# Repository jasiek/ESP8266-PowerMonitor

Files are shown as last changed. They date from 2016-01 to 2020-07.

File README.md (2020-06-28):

# ESP8266-PowerMonitor

See this project on 

Uses [Lets Control It/ESP Easy](https://www.letscontrolit.com/).

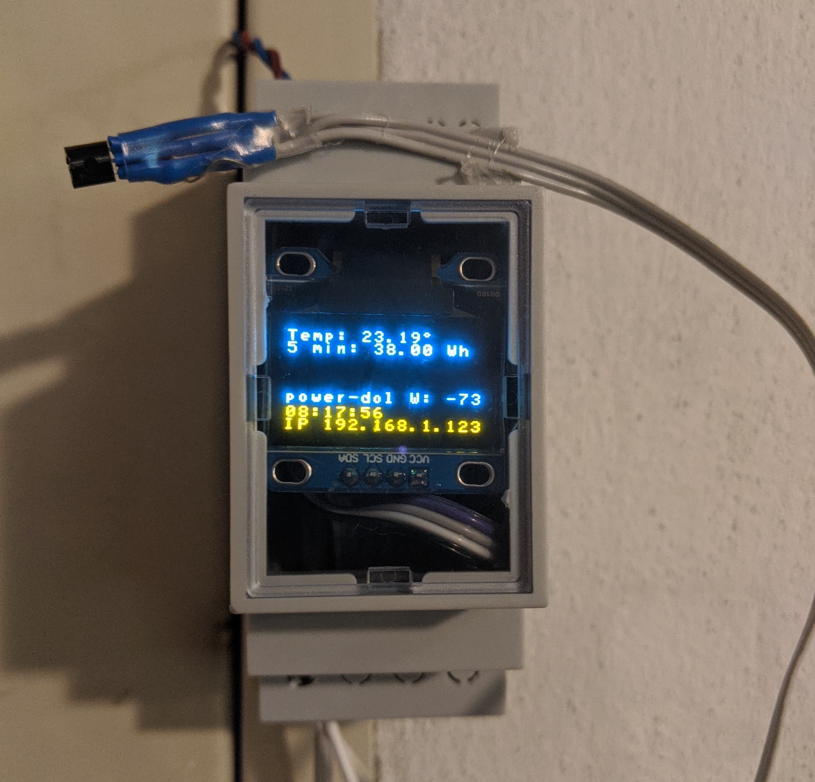
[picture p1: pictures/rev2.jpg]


## Programming

Download the latest [ESP Easy Mega release](https://github.com/letscontrolit/ESPEasy/releases).

Install [esptool.py](https://github.com/espressif/esptool). Hook up a USB-to-serial adapter to the board.

Short `_PROG` & `GND` and press RESET.

Find the right firmware file (`normal_ESP8266_4M1M`) and run:

```
$ esptool.py --port /dev/cu.usbserial-14120 --baud 115200 write_flash 0 ESP_Easy_mega_20200516_normal_ESP8266_4M1M.bin
```

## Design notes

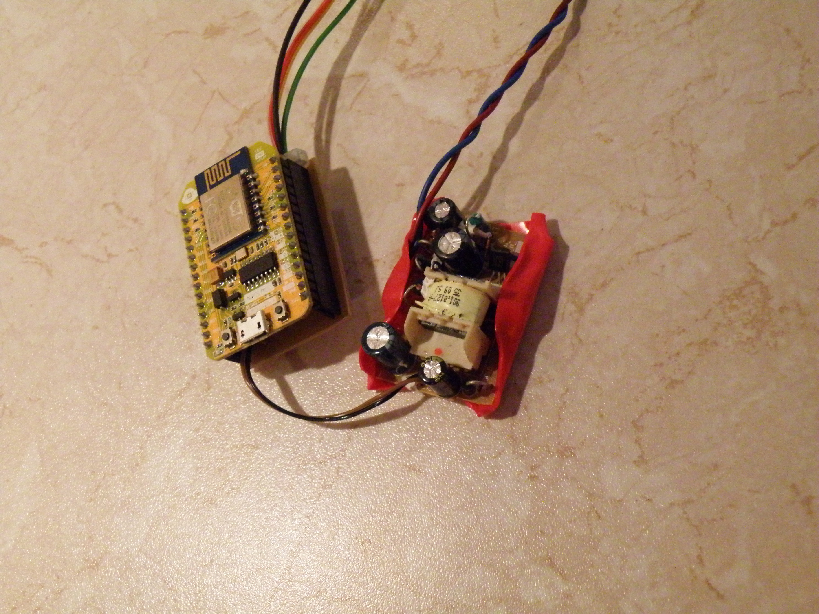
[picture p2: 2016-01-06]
pictures/NO_PIR_bare2.jpg

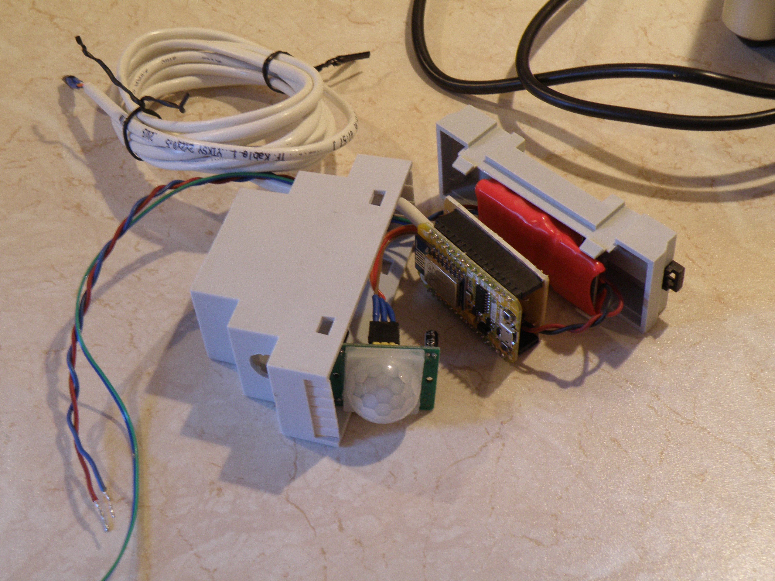
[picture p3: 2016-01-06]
pictures/PIR_exploded.jpg

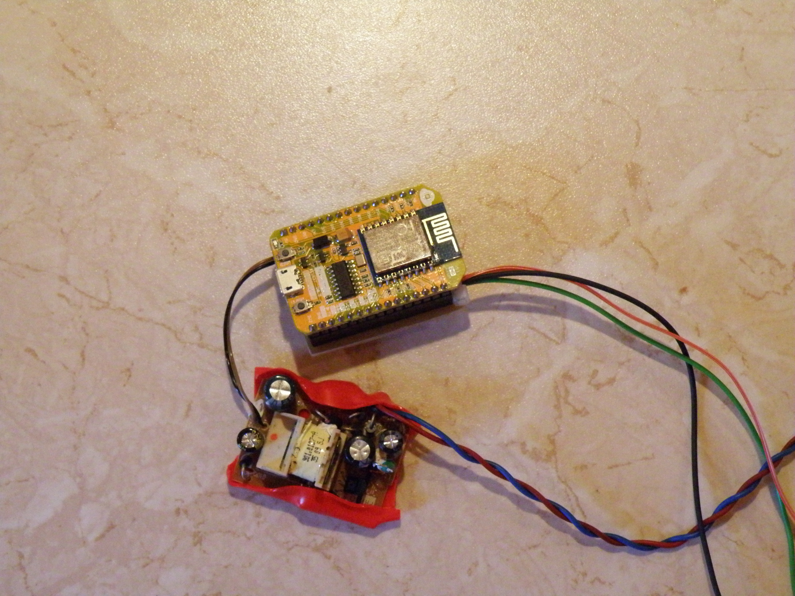
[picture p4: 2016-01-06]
pictures/NO_PIR_bare.jpg

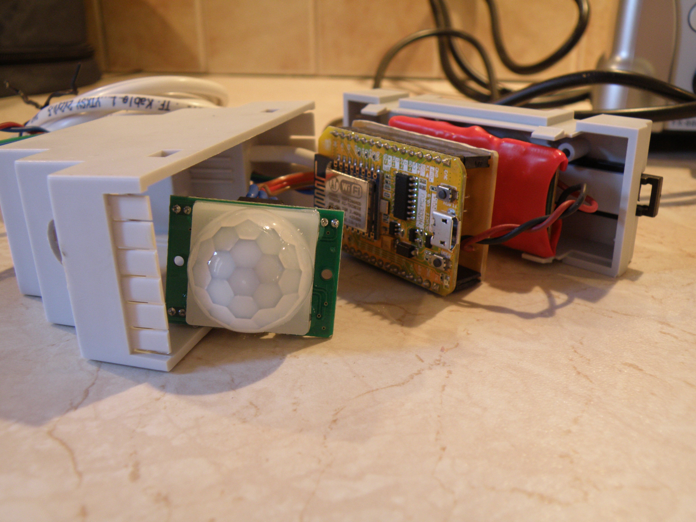
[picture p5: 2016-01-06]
pictures/PIR_exploded2.jpg

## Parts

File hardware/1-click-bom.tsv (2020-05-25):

References | Qty | Description
C1 | 1 | C 0.1uF Unpolarized capacitor 1206 3216Metric Pad1.42x1.75mm HandSolder
C2 | 1 | CP 10uF Polarized capacitor Elec 4x5.3
C3 | 1 | C 100nF Unpolarized capacitor 1206 3216Metric Pad1.42x1.75mm HandSolder
F1 | 1 | Polyfuse 100mA Resettable fuse, polymeric positive temperature coefficient Fuse 1206 3216Metric Pad1.42x1.75mm HandSolder
J1 | 1 | Conn 01x02 Male CONN PULSE Generic connector, single row, 01x02, script generated (kicad-library-utils/schlib/autogen/connector/) PinHeader 1x02 P2.54mm Vertical
J2 | 1 | Conn 01x05 Male CONN PROG Generic connector, single row, 01x05, script generated (kicad-library-utils/schlib/autogen/connector/) PinHeader 1x05 P2.54mm Vertical
J3 | 1 | Conn 01x02 Male CONN AC Generic connector, single row, 01x02, script generated (kicad-library-utils/schlib/autogen/connector/) TerminalBlock bornier-2 P5.08mm
J4 | 1 | Conn 01x03 Male CONN TEMP Generic connector, single row, 01x03, script generated (kicad-library-utils/schlib/autogen/connector/) PinHeader 1x03 P2.54mm Vertical
J5 | 1 | Conn 01x04 Male CONN I2C Generic connector, single row, 01x04, script generated (kicad-library-utils/schlib/autogen/connector/) PinHeader 1x04 P2.54mm Vertical
JP1 | 1 | SolderJumper 2 Open 3.3V BYPASS Solder Jumper, 2-pole, open SolderJumper-2 P1.3mm TrianglePad1.0x1.5mm
PS1 | 1 | HLK-PM03 Compact AC/DC board mount power module 3W 5V Converter ACDC HiLink HLK-PMxx
R1, R2, R4, R6, R5 | 5 | R 10k Resistor 1206 3216Metric Pad1.42x1.75mm HandSolder
R3 | 1 | R 470 Resistor 1206 3216Metric Pad1.42x1.75mm HandSolder
R7 | 1 | R 4.7k Resistor 1206 3216Metric Pad1.42x1.75mm HandSolder
SW1 | 1 | SW DIP x01 RESET 1x Switch, Single Pole Throw (SPST) switch, small symbol Push 1P1T NO 6x6mm H9.5mm
U1 | 1 | AMS1117-3.3 1A Low Dropout regulator, positive, 1.5V fixed output, SOT-223 SOT-223-3 TabPin2
U2 | 1 | ESP-12F 802.11 b/g/n Wi-Fi Module ESP-12E

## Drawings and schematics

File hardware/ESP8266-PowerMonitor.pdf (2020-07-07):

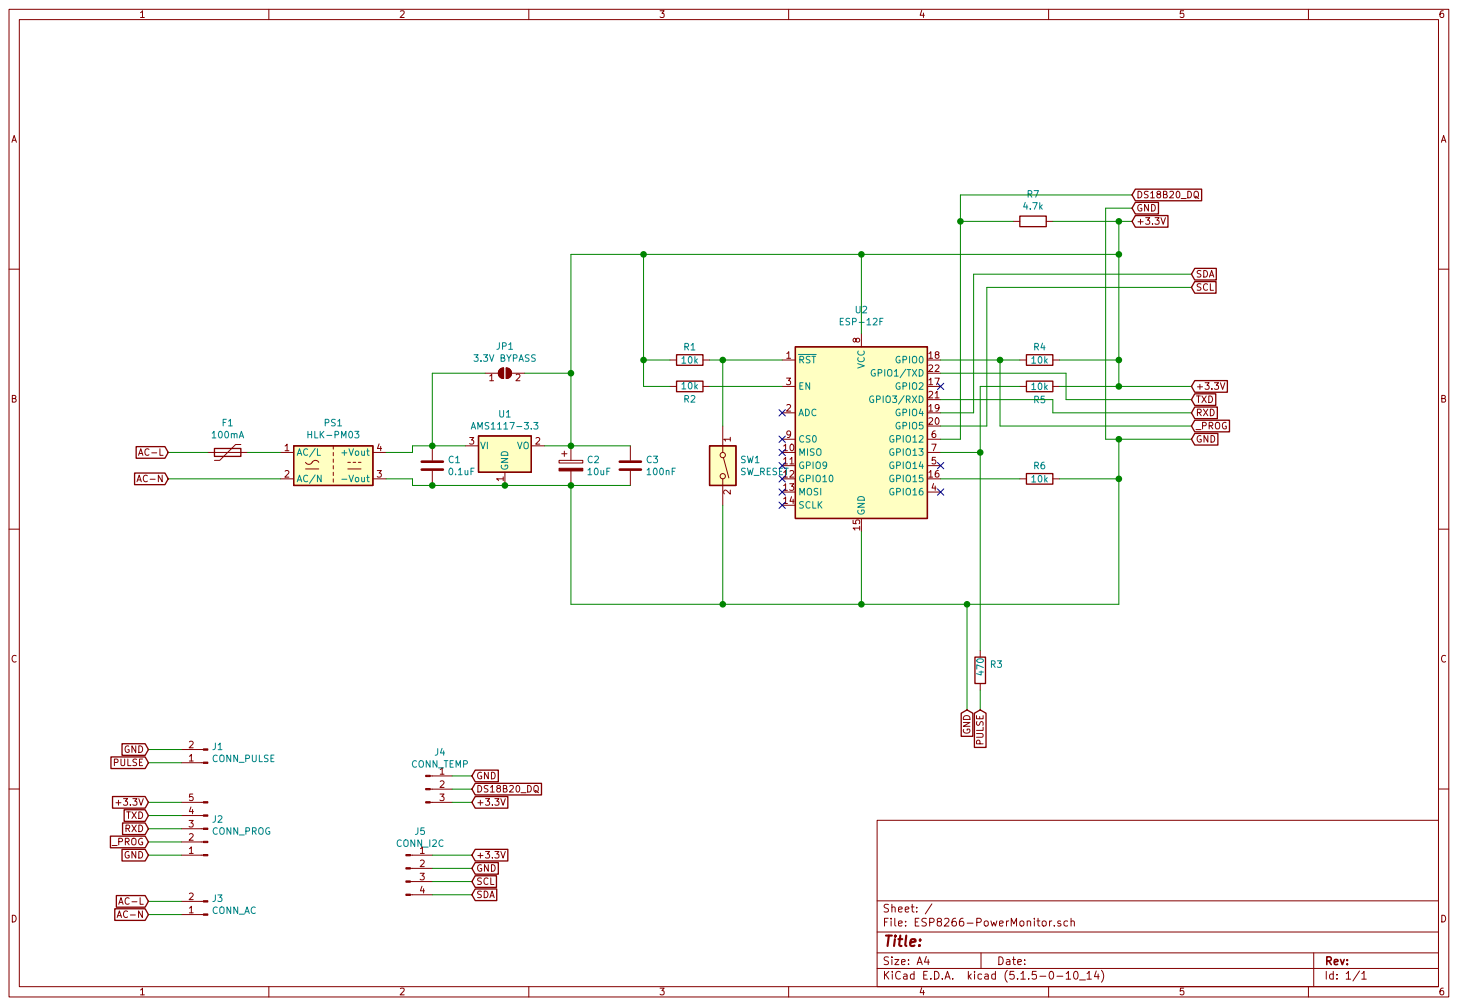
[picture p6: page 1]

Id: 1/1 Title: File: ESP8266-PowerMonitor.sch Sheet: /

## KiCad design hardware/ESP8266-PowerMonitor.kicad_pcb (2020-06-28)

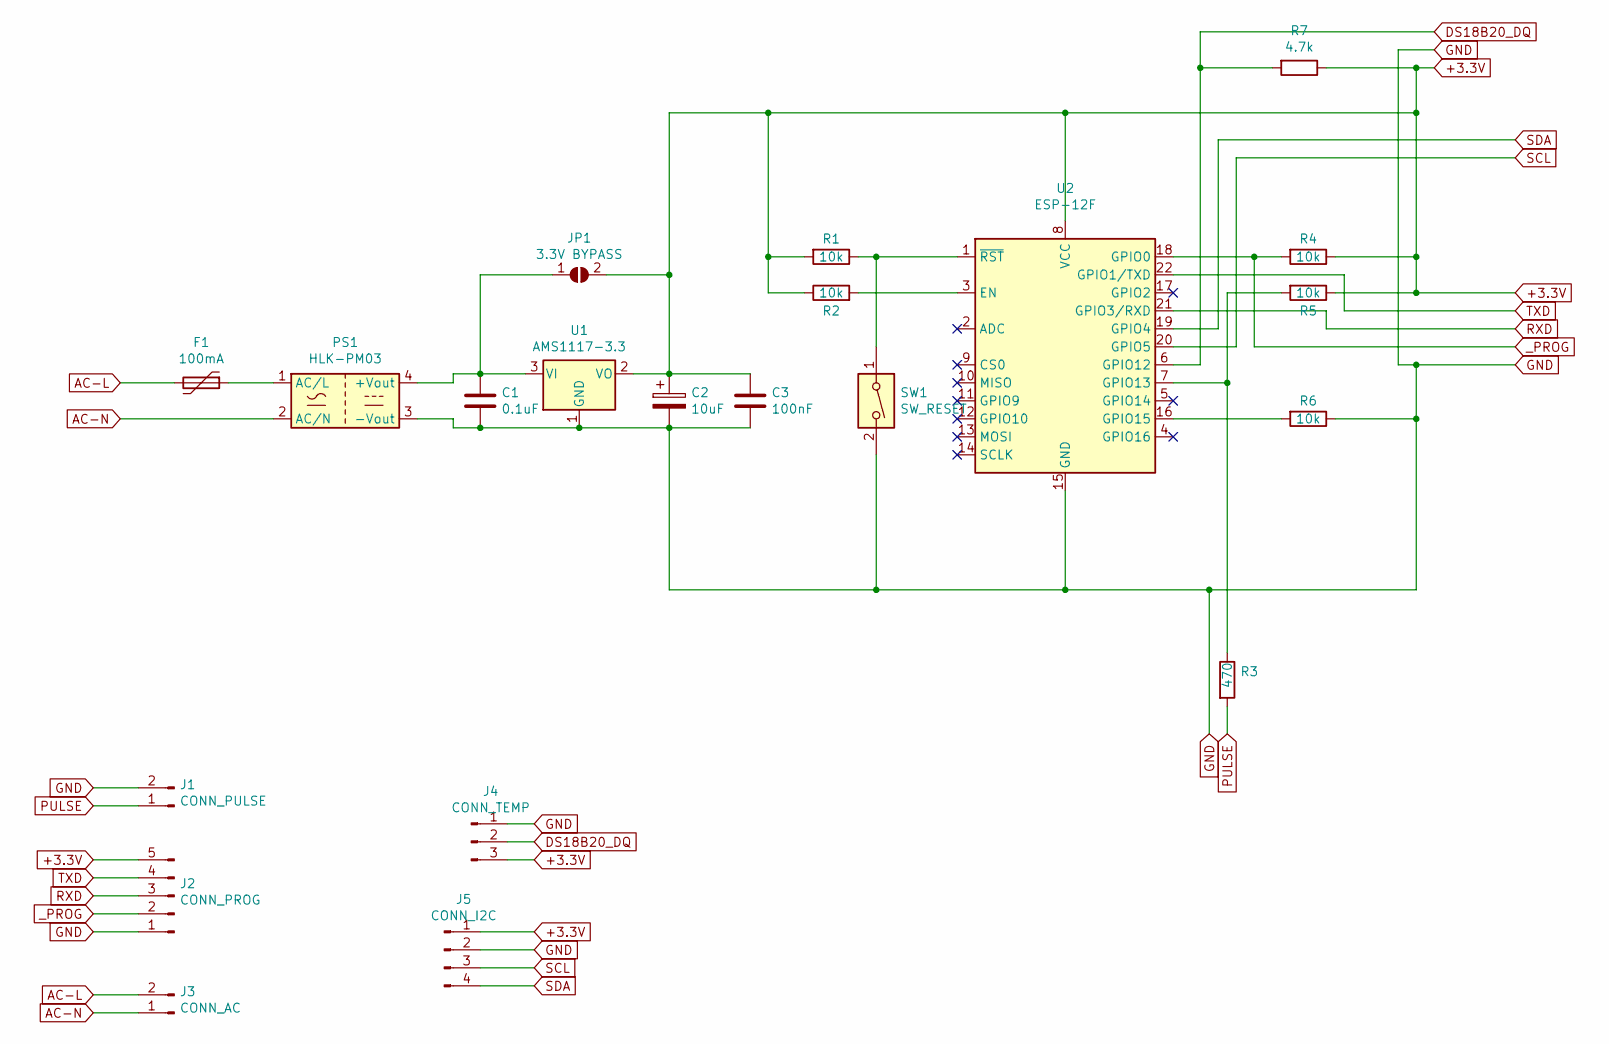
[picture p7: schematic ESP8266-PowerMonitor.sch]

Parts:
C1: 0.1uF; C_1206_3216Metric_Pad1.42x1.75mm_HandSolder
C2: 10uF; CP_Elec_4x5.3
C3: 100nF; C_1206_3216Metric_Pad1.42x1.75mm_HandSolder
F1: 100mA; Fuse_1206_3216Metric_Pad1.42x1.75mm_HandSolder
J1: CONN_PULSE; PinHeader_1x02_P2.54mm_Vertical
J2: CONN_PROG; PinHeader_1x05_P2.54mm_Vertical
J3: CONN_AC; TerminalBlock_bornier-2_P5.08mm
J4: CONN_TEMP; PinHeader_1x03_P2.54mm_Vertical
J5: CONN_I2C; PinHeader_1x04_P2.54mm_Vertical
JP1: 3.3V BYPASS; SolderJumper-2_P1.3mm_Open_TrianglePad1.0x1.5mm
PS1: HLK-PM03; Converter_ACDC_HiLink_HLK-PMxx
R1, R2, R4, R5, R6: 10k; R_1206_3216Metric_Pad1.42x1.75mm_HandSolder
R3: 470; R_1206_3216Metric_Pad1.42x1.75mm_HandSolder
R7: 4.7k; R_1206_3216Metric_Pad1.42x1.75mm_HandSolder
SW1: SW_RESET; SW_Push_1P1T_NO_6x6mm_H9.5mm
U1: AMS1117-3.3; SOT-223-3_TabPin2
U2: ESP-12F; ESP-12E

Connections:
+3.3V: C2.1, C3.1, J2.5, J4.3, J5.1, JP1.2 (B), R1.2, R2.1, R4.1, R5.1, R7.1, U1.2 (VO), U2.8 (VCC)
AC-L: F1.2, J3.2
AC-N: J3.1, PS1.2 (AC/N)
DS18B20_DQ: J4.2, R7.2, U2.6 (GPIO12)
GND: C1.2, C2.2, C3.2, J1.2, J2.1, J4.1, J5.2, PS1.3 (-Vout), R6.1, SW1.2, U1.1 (GND), U2.15 (GND)
unnamed: C1.1, JP1.1 (A), PS1.4 (+Vout), U1.3 (VI)
unnamed: F1.1, PS1.1 (AC/L)
unnamed: R1.1, SW1.1, U2.1 (~RST)
unnamed: R2.2, U2.3 (EN)
unnamed: R3.1, R5.2, U2.7 (GPIO13)
unnamed: R6.2, U2.16 (GPIO15)
PULSE: J1.1, R3.2
RXD: J2.3, U2.21 (GPIO3/RXD)
SCL: J5.3, U2.20 (GPIO5)
SDA: J5.4, U2.19 (GPIO4)
TXD: J2.4, U2.22 (GPIO1/TXD)
_PROG: J2.2, R4.2, U2.18 (GPIO0)

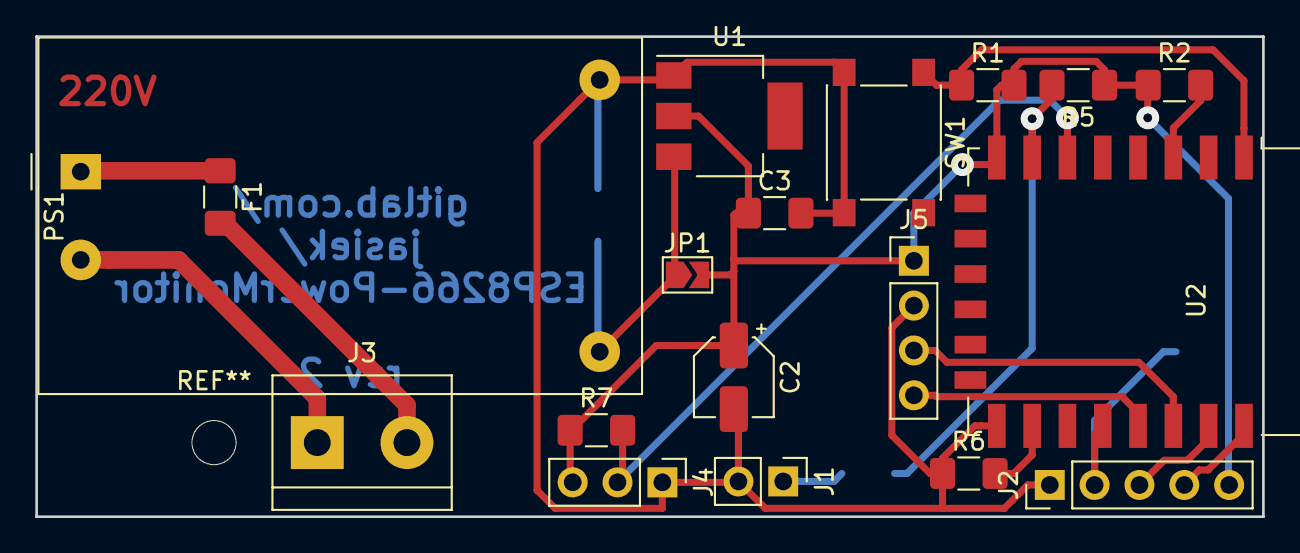
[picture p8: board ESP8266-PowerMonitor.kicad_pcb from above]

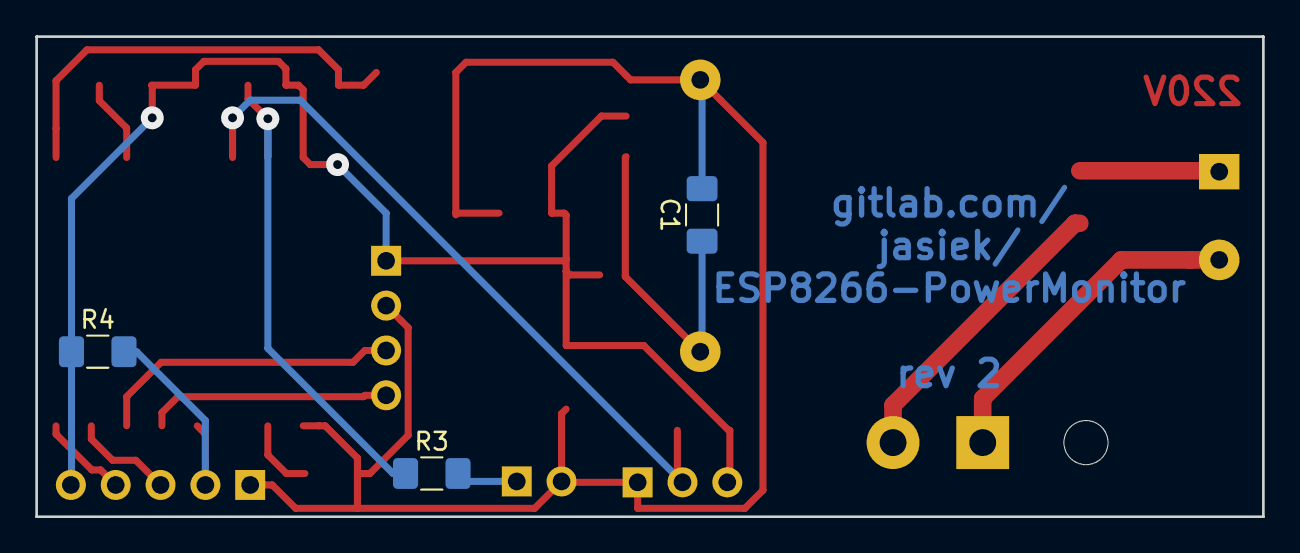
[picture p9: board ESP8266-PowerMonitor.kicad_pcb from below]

Board: 2 copper layers, 69.5 x 27.2 mm, 21 parts (3 on the bottom side), 17 nets.

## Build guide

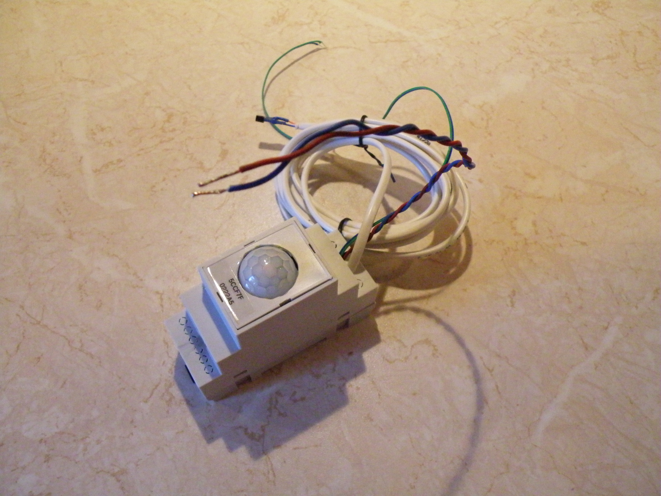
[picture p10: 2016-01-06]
pictures/PIR_assembled.jpg

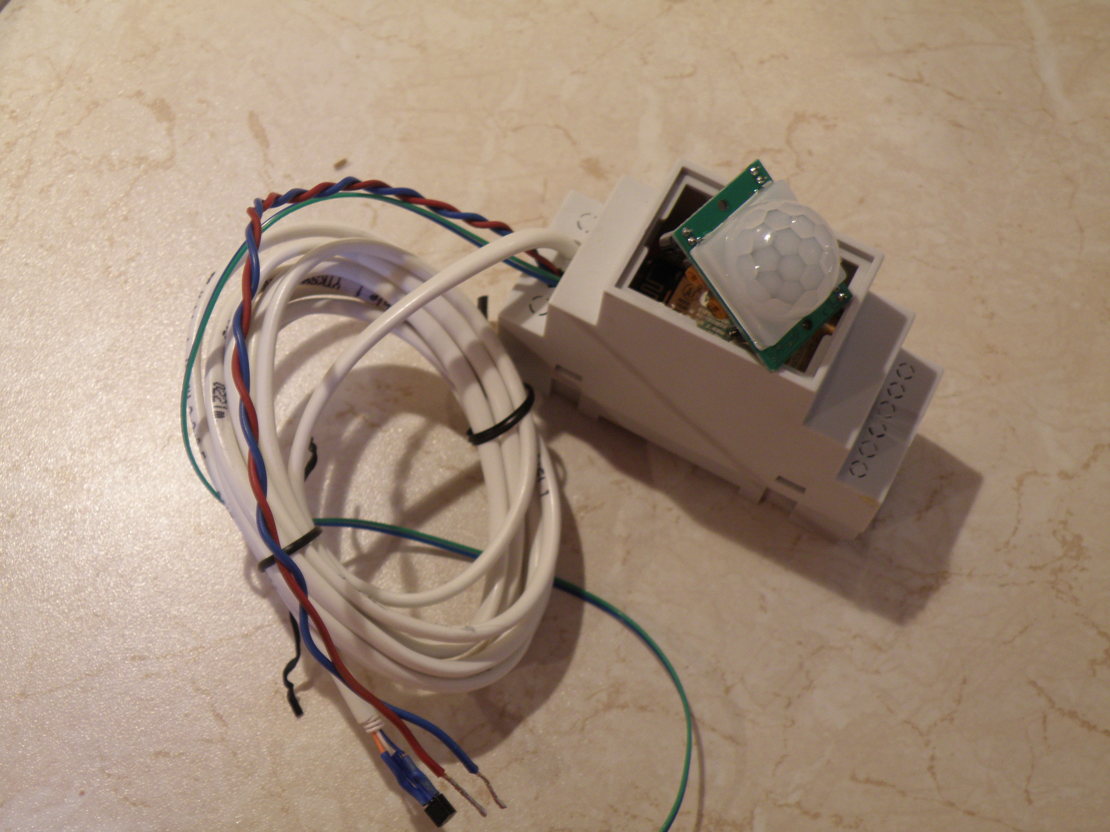
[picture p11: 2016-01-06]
pictures/PIR_semi-assembled.jpg

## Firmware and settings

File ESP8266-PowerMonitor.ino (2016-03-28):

#include <ArduinoJson.h>
#include <Ticker.h>
#include <DallasTemperature.h>
#include <OneWire.h>
#include <ESP8266WiFi.h>
#include <ESP8266WiFiMulti.h>
#include <ESP8266HTTPClient.h>
#include <ESP8266mDNS.h>
#include "IPAddress.h"
#include "settings.h"
#include "string.h"

#define PULSE_PIN 2
#define ONEWIRE_PIN 4
#define PIR_PIN 5
#define LED_PIN 16
// Report frequency is in seconds
#define REPORT_FREQUENCY 300

ADC_MODE(ADC_VCC);

OneWire bus(ONEWIRE_PIN); // Use GPIO4 as it is not connected to any peripherals
DallasTemperature sensors(&bus);
Ticker readAndReport;
ESP8266WiFiMulti WiFiMulti;

String nodeName;
int movementCounter;
int energyCounter;
int errorCounter;
unsigned long pulseStartTime;
unsigned long pulseWidth;
unsigned long packetsSent;
float voltage;
float temperature;
int rssi;

void pulseStart();
void pulseEnd();
void determineNodeName();
void recordMovement();
void report();
void attemptSensorReadAndReport();
void maybeReconnect();

void setup() {
  Serial.begin(115200);
  Serial.println();
  
  WiFiMulti.addAP(WIFI_SSID, WIFI_PASS);

  maybeReconnect();
  determineNodeName();
  // When there's a pulse, increment the counter.
  pulseStartTime = millis();
  pinMode(PIR_PIN, INPUT);
  pinMode(PULSE_PIN, INPUT);
  pinMode(LED_PIN, OUTPUT); // Used for signalling errors
  digitalWrite(LED_PIN, HIGH);
  attachInterrupt(PULSE_PIN, pulseStart, FALLING);
  attachInterrupt(PIR_PIN, recordMovement, RISING);
  attemptSensorReadAndReport();
}

void error(int num) {
  int i = 0;
  digitalWrite(LED_PIN, HIGH);
  for (i = 0; i < num; i++) {
    digitalWrite(LED_PIN, LOW);
    delay(100);
    digitalWrite(LED_PIN, HIGH);
    delay(100);
  }
}

void loop() {
  delay(REPORT_FREQUENCY * 1000);
  attemptSensorReadAndReport();
}

void recordMovement() {
  movementCounter++;
}

void pulseStart() {
  // are we rising or falling?
  unsigned long now = millis();
  pulseStartTime = now;
  attachInterrupt(PULSE_PIN, pulseEnd, RISING);
}

void pulseEnd() {
  unsigned long now = millis();
  pulseWidth = now - pulseStartTime;
  if (pulseWidth > METER_PULSE_WIDTH - 15 && pulseWidth < METER_PULSE_WIDTH + 15) {
    // workaround?
    energyCounter++;
  }
  attachInterrupt(PULSE_PIN, pulseStart, FALLING);
}

void report() {
  maybeReconnect();
  Serial.println(millis());
  Serial.println("Sending data");

  voltage = ESP.getVcc() / 1000.0;
  rssi = WiFi.RSSI();
  temperature = sensors.getTempCByIndex(0);

  HTTPClient http;
  http.begin(String(API_ENDPOINT) + nodeName);
  String stream;
  StaticJsonBuffer<200> buffer;
  JsonObject& root = buffer.createObject();
  root["temperature"] = temperature;
  root["movementCounter"] = movementCounter;
  root["energyCounter"] = 1.0f * energyCounter / PULSE_PER_WH;
  root["errorCounter"] = errorCounter;
  root["voltage"] = voltage;
  root["rssi"] = rssi;
  root["packetsSent"] = packetsSent;
  root["uptime"] = millis();
  root.printTo(stream);
  Serial.println(stream);

  int status = http.POST(stream);
  if (status == 200) {
    Serial.println("...success!");
    packetsSent++;
    movementCounter = 0;
    energyCounter = 0;
  } else {
    Serial.println(status);
    Serial.println(http.getString());
    errorCounter++;
  }
  Serial.println("end");
  
  http.end();
}

void maybeReconnect() {
  while (WiFiMulti.run() != WL_CONNECTED) {
    Serial.println("(Re)connecting...");
    delay(1000);
  }
  Serial.print("connected, got IP: ");
  Serial.println(WiFi.localIP());
}

void determineNodeName() {
  nodeName = WiFi.macAddress();
  for (int i = nodeName.indexOf(':'); i > -1; i = nodeName.indexOf(':')) nodeName.remove(i, 1);
  nodeName.toLowerCase();

  Serial.print("Node name: ");
  Serial.println(nodeName);

  MDNS.begin(nodeName.c_str());
  MDNS.addService("http", "tcp", 80);
}

void attemptSensorReadAndReport() {
  sensors.begin();
  int tries = 0;
  bool success = false;
  // Problems with EM interference? Just retry...
  while (tries < 10) {
    success = sensors.getDeviceCount() > 0;
    if (success) break;
    delay(500);
    sensors.begin();
    tries++;
  }

  if (success) {
    sensors.setResolution(12);
    sensors.requestTemperatures();
    report();
  } else {
    errorCounter++;
    error(tries);
  }
}

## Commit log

2015-12-07 Started sketching PCBs etc.
    [ESP8266-PowerMonitor.kicad_pcb, ESP8266-PowerMonitor.sch]
2015-12-11 Added the rest of wires + 1wire bus.
    [ESP8266-PowerMonitor.sch]
2015-12-11 A few updates to the scheamtics.
    [ESP8266-PowerMonitor.sch]
2015-12-13 Added DS18B20 temperature sensor and a PIR sensor.
2015-12-14 Added error count tracking to see how many transfers are unsuccessful.
    [ESP8266-PowerMonitor.ino]
2015-12-14 Almost done with the board.
    [ESP8266-PowerMonitor.sch]
2015-12-15 Production prints.
    [ESP8266-PowerMonitor.kicad_pcb, ESP8266-PowerMonitor.sch]
2015-12-27 statsd class shamelessly ripped off from https://github.com/zackkitzmiller/statsd-arduino
2015-12-28 Report temperature, movement and power consumption - initial testing.
2015-12-30 Report RSSI and voltage.
2015-12-30 Report RSSI and voltage. RSSI reported has to be a positive value, otherwise statsd thinks we're dealing with deltas.
2015-12-30 Node name is now set correctly, to the mac address of the device. RSSI and temperature are reported by first setting the value to 0 to allow for negative values. RSSI is reported as a negative value.
    [ESP8266-PowerMonitor.ino]
2016-01-01 Error signalling using an LED on GPIO16.
    [ESP8266-PowerMonitor.ino]
2016-01-01 Fixed a few typos.
    [ESP8266-PowerMonitor.ino]
2016-01-01 Updated schematics & PCB.
    [ESP8266-PowerMonitor.kicad_pcb, ESP8266-PowerMonitor.sch]
2016-01-02 EM interference should no longer prevent the 1 wire bus from working.
    [ESP8266-PowerMonitor.ino]
2016-01-04 Updated netlist and footprints.
    [ESP8266-PowerMonitor.sch]
2016-01-06 Changed 4.7k resistor to 2.2k to facilitate greater 1 wire length.
    [ESP8266-PowerMonitor.sch]
2016-01-06 Improved, complete PCB, pre-panelized.
    [ESP8266-PowerMonitor.kicad_pcb]
2016-01-06 Removed old plot, added a new, panelized plot and PCB.
    [ESP8266-PowerMonitor-PCB_Array.kicad_pcb]
2016-01-08 Generated new top-left corner aligned PCB and drill files.
    [ESP8266-PowerMonitor-PCB_Array-NPTH.drl, ESP8266-PowerMonitor-PCB_Array.drl]
2016-01-27 Chain statsd metrics, bump resolution to 12 bits (why not?).
2016-03-26 Fixed HTTP client, requires the use of WiFiMulti...
    [ESP8266-PowerMonitor.ino]
2016-03-28 Using ticket callbacks doesn't work for some reason.
    [ESP8266-PowerMonitor.ino]
2016-10-03 Force a reset after reporting results, there's an issue with lock up of some sort.
    [ESP8266-PowerMonitor.ino]
2016-10-05 ESP.restart() doesn't work reliably, got rid of it. Removed ticker which wasn't used anywhere. Added more verbose reporting of what the device is up to atm.
    [ESP8266-PowerMonitor.ino]
2016-10-06 ESP.restart() fix.
    https://github.com/esp8266/Arduino/issues/1017#issuecomment-200605576
    https://github.com/esp8266/Arduino/blob/master/doc/faq/readme.md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
    [ESP8266-PowerMonitor.ino]
2016-10-07 Print out the measured pulse width, for debugging purposes.
2019-12-28 Bumped dependencies to the latest version of metering. Removed logic around classifying which power sensor is used - as long as there's a pulse < 90ms we will count it. Added ICACHE_RAM_ATTR attribut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
2019-12-28 Do not restart the sensor.
2020-04-24 Redesigned the board.
    [ESP8266-PowerMonitor-B_Adhes.gbr, ESP8266-PowerMonitor-B_CrtYd.gbr, ESP8266-PowerMonitor-B_Cu.gbr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]
2020-04-27 * Reworked the board to use 0.5/1.3mm vias. * Added I2C to GPIO4/5 in case we want to use an OLED display. * Moved the pulse pin to GPIO2 (pulled up). * Re-orged the board to use fewer vias.
    [ESP8266-PowerMonitor-B_Adhes.gbr, ESP8266-PowerMonitor-B_CrtYd.gbr, ESP8266-PowerMonitor-B_Cu.gbr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]
2020-05-25 Updated PCB, uses GPIO13 instead of GPIO2, which didn't work.
    [ESP8266-PowerMonitor-B_Adhes.gbr, ESP8266-PowerMonitor-B_CrtYd.gbr, ESP8266-PowerMonitor-B_Cu.gbr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]
2020-05-25 Enable project on kitspace.org
    [1-click-bom.tsv]
2020-05-25 Further kitspace tweaks.
    [1-click-bom.tsv]
2020-06-25 Added a link to order a PCB.
2020-06-28 Revision 2 PCB done.
    [ESP8266-PowerMonitor-B_Adhes.gbr, ESP8266-PowerMonitor-B_CrtYd.gbr, ESP8266-PowerMonitor-B_Cu.gbr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]
2020-07-07 Added PDF of the schematic.
